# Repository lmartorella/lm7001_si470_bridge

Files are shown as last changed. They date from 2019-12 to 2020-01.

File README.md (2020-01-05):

# LM7001 FM tuner board upgrade to Si470x 

## Why

I needed a simple replacement for a vintage Pioneer Hi-fi radio tuner that tends to mute quite often. As most Pioneer units of 90's era, his MCU is the core part of the whole system (it receives the IR commands, it displays messages and implements the wake-up timers).

Luckily, the malfunctioning tuner board is based on the LM7001, a direct digital PLL synthesizer with simple serial interface. The PLL works perfectly, so the issue with the jittering sound should be in some other part of the tuner board.

After some hours spent to try to repair the board, I went for the simplest digital upgrade.

## The Silicon Labs module

It is very easy now to found a complete FM tuner with RDS for a couple of dollars from China suppliers. 

The most common core chip is the [Si4702](https://www.silabs.com/audio-and-radio/fm-radios/si4702-03-radio-receivers) from Silicon Labs.

His I2C interface makes it suitable for interfacing to virtually any MCU.

It exposes the mono/stereo state and the tuned flags via I2C: what we need to allow the original Pioneer display to show such information to the user, and to allow auto-scan.

## The Microchip MCU as interface

The computational power to decode the Pioneer MCU commands sent to the LM7001 requires little resources. So I picked up a discontinued but handy 4MHz PIC16F628 from my stock.

> Note: this old PIC supports very little debug facilities. In addition it doesn't support ICSP programming at 3.3V (WTF), so I added a manual jumper to in-circuit program my prototype. Consider any newer non-discontinued 8-bit PIC MCU as an upgrade for your projects. 

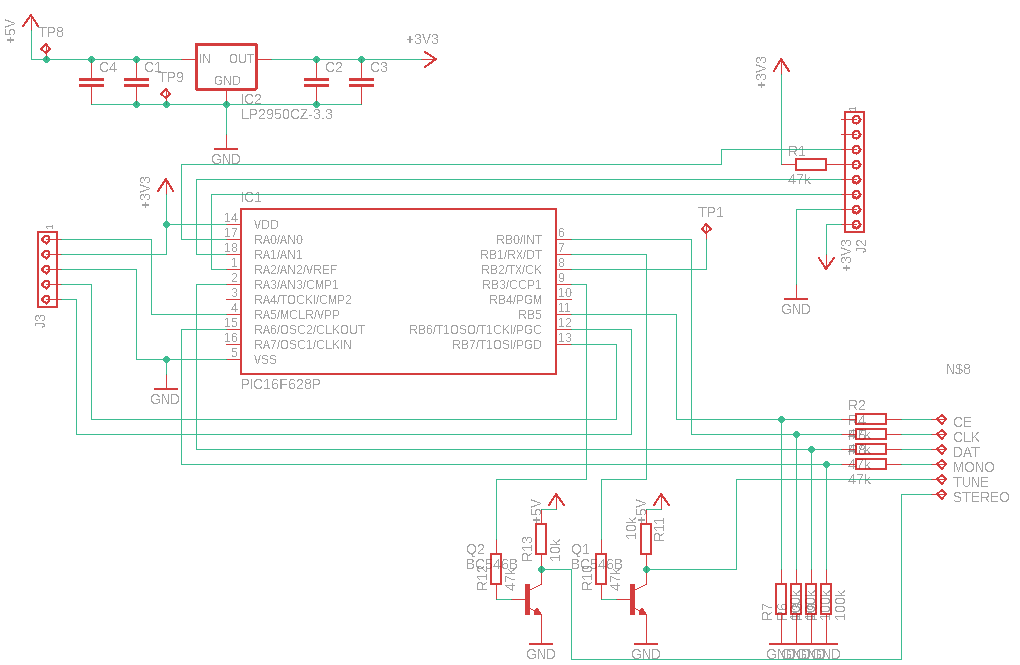
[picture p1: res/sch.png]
The schematic


In addition to decode the signals to control the LM7001, I wired the MONO signal and sent back the TUNED and STEREO lines as well. In that way all the Pioneer unit functions are fully functionals (all but the AM band).

The 5V TTL lines are converted to 3.3V inputs with resistors, and the two output converted back with a couple of NPNs.

The LM7001 lines are sampled using interrupts (RB0/INT for the chip enable line that triggers the start of transmission, and RB change for the clock line).

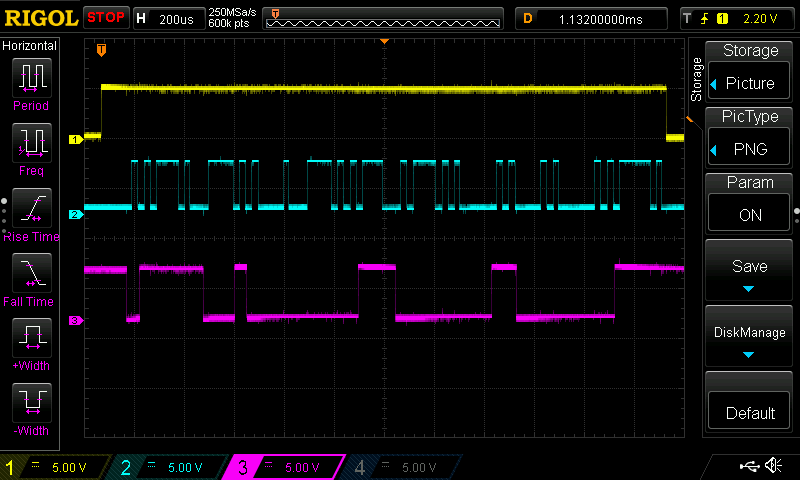
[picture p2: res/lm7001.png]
LM7001 timings

_The Pioneer MCU probably implemented the transmission in firmware due to the jittering of the high CLK line._

*IMPORTANT*: The response time from the end of tuning command to when the TUNED signal is drive high in case of valid FM station should be fast enough in order to let the Pioneer MCU to properly scan the frequencies in auto-scan mode.

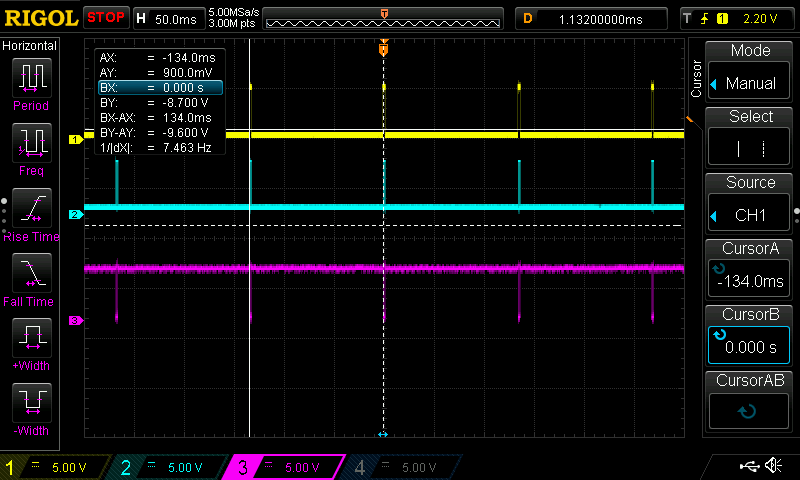
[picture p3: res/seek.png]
seeking

_In that case, it seems that the unit auto-scans with an interval of ~130ms._

## The final result

The modification here - not looking so professional with all these wires around - is however completely reversible for future reworks.

The board is manaully wired on a small piece of a prototype board to save bucks (but not to save time).

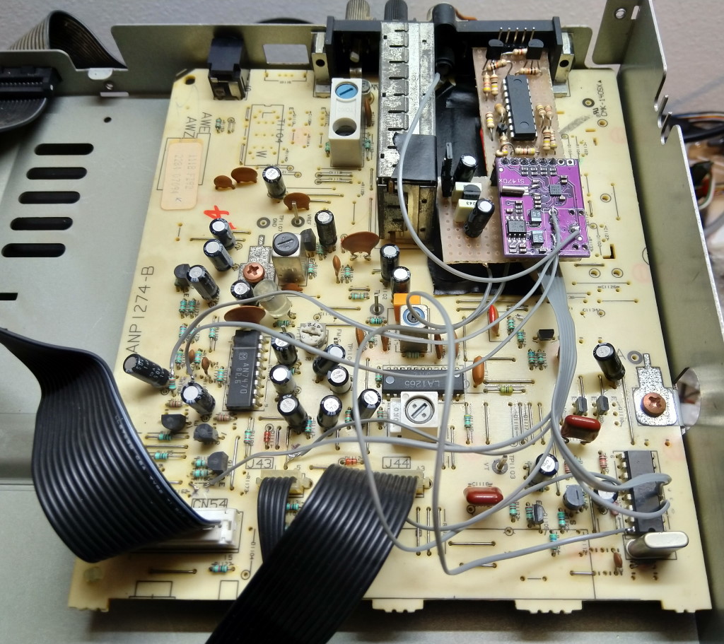
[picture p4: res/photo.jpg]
The board


It is fascinating to note that the whole tuner board now fits in the smaller 2x2mm chip in the purple module! The other bigger SSOP8 chip is the on-board headphone amplifier that I didn't even bother to remove.

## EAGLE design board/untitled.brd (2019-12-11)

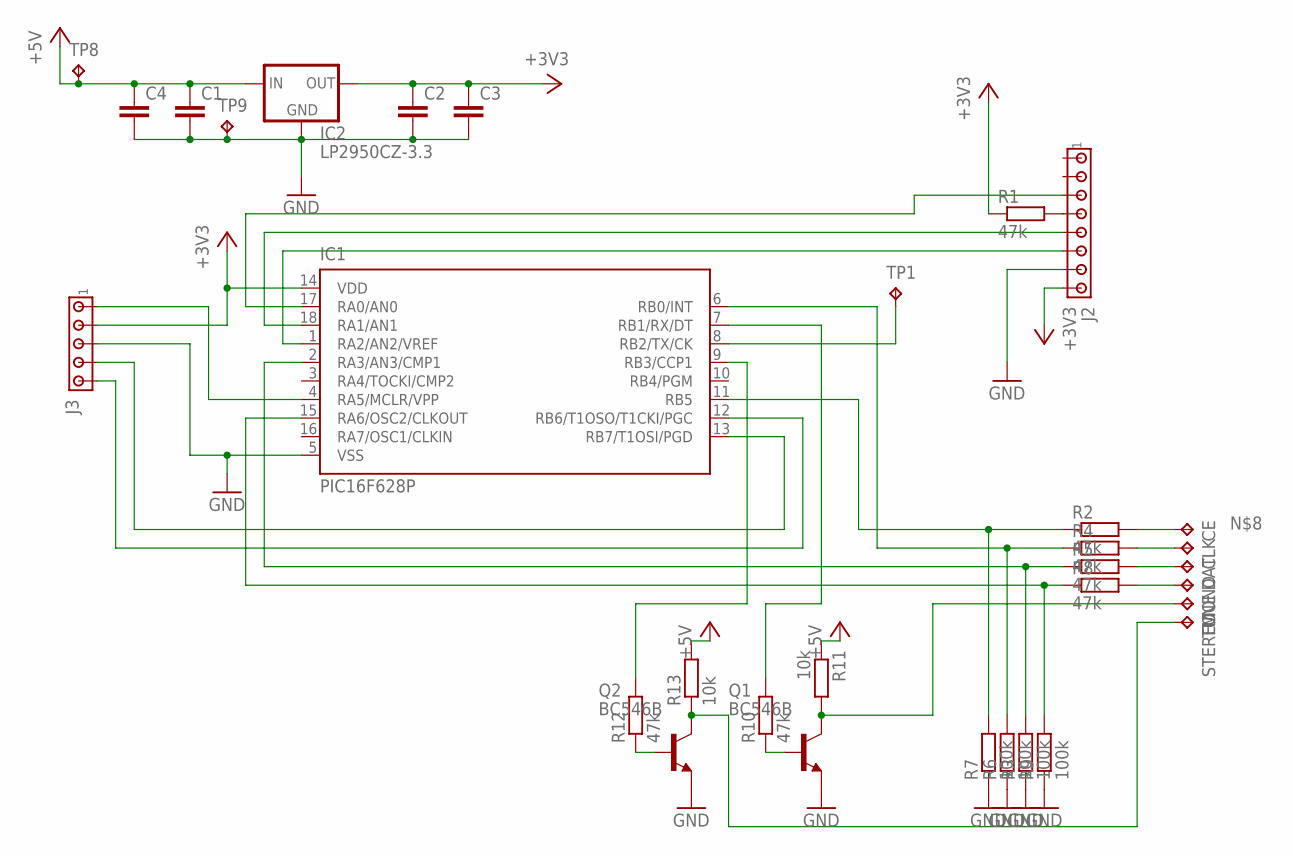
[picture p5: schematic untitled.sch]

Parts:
C1, C2, C3, C4: C-EU025-024X044; C025-024X044
CE: TPB1,27; B1,27
CLK: TPB1,27; B1,27
DAT: TPB1,27; B1,27
IC1: PIC16F628P; DIL18
IC2: LP2950CZ-3.3; TO92
J2: MTA08-100; 10X08MTA
J3: MTA05-100; 10X05MTA
MONO: TPB1,27; B1,27
Q1, Q2: BC546B; TO92-EBC
R1, R2, R4, R5, R8, R10, R12: 47k; 0204/7
R3, R6, R7, R9: 100k; 0204/7
R11, R13: 10k; 0204/7
STEREO: TPB1,27; B1,27
TP1, TP8, TP9: TPB1,27; B1,27
TUNE: TPB1,27; B1,27

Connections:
+3V3: C2.1, C3.1, IC1.14 (VDD), IC2.1 (OUT), J2.8, J3.2, R1.1
+5V: C1.1, C4.1, IC2.3 (IN), R11.1, R13.2, TP8.TP
GND: C1.2, C2.2, C3.2, C4.2, IC1.5 (VSS), IC2.2 (GND), J2.7, J3.3, Q1.E, Q2.E, R3.1, R6.1, R7.1, R9.1, TP9.TP
unnamed: IC1.4 (RA5/MCLR/VPP), J3.1
unnamed: IC1.1 (RA2/AN2/VREF), J2.6
unnamed: IC1.18 (RA1/AN1), J2.5
unnamed: IC1.13 (RB7/T1OSI/PGD), J3.4
unnamed: IC1.12 (RB6/T1OSO/T1CKI/PGC), J3.5
unnamed: J2.4, R1.2
unnamed: IC1.17 (RA0/AN0), J2.3
unnamed: CE.TP, R2.2
unnamed: IC1.8 (RB2/TX/CK), TP1.TP
unnamed: CLK.TP, R4.2
unnamed: DAT.TP, R5.2
unnamed: IC1.2 (RA3/AN3/CMP1), R3.2, R5.1
unnamed: IC1.6 (RB0/INT), R4.1, R6.2
unnamed: IC1.11 (RB5), R2.1, R7.2
unnamed: Q1.C, R11.2, TUNE.TP
unnamed: Q1.B, R10.1
unnamed: MONO.TP, R8.2
unnamed: IC1.15 (RA6/OSC2/CLKOUT), R8.1, R9.2
unnamed: Q2.C, R13.1, STEREO.TP
unnamed: IC1.7 (RB1/RX/DT), R10.2
unnamed: Q2.B, R12.1
unnamed: IC1.9 (RB3/CCP1), R12.2

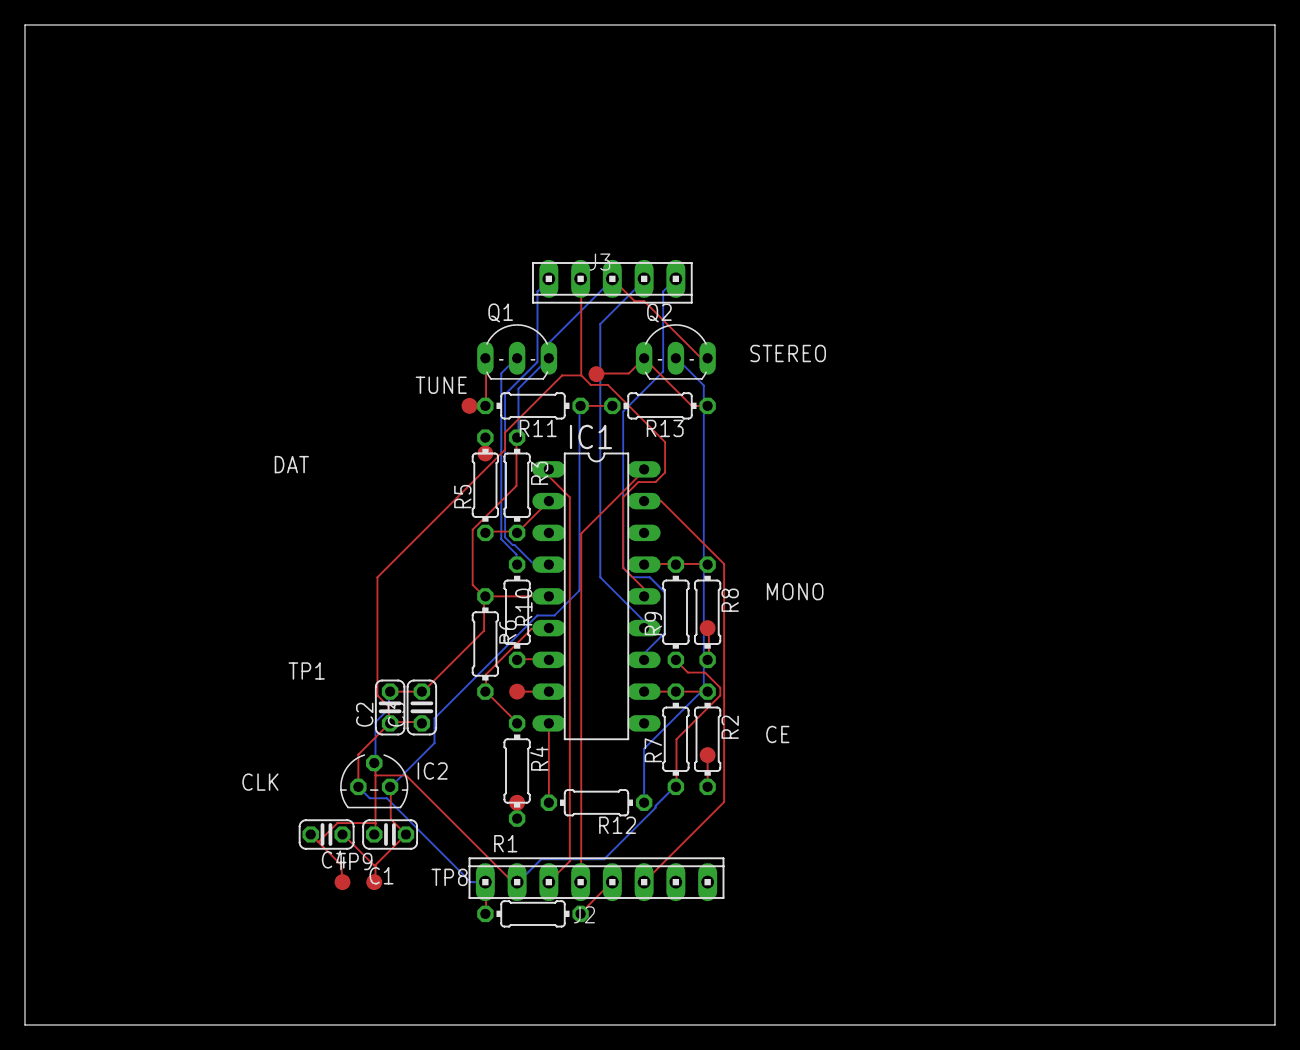
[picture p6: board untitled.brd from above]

Board: 2 copper layers, 100.0 x 80.0 mm, 32 parts (0 on the bottom side), 25 nets.

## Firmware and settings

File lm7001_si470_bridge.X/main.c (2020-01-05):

// CONFIG
#pragma config FOSC = INTOSCIO  // Oscillator Selection bits (INTOSC oscillator: I/O function on RA6/OSC2/CLKOUT pin, I/O function on RA7/OSC1/CLKIN)
#pragma config WDTE = ON        // Watchdog Timer Enable bit (WDT enabled)
#pragma config PWRTE = ON       // Power-up Timer Enable bit (PWRT enabled)
#pragma config MCLRE = ON       // RA5/MCLR/VPP Pin Function Select bit (RA5/MCLR/VPP pin function is MCLR)
#pragma config BOREN = OFF      // *** 3.3V! Brown-out Detect Enable bit (BOD enabled)
#pragma config LVP = OFF        // Low-Voltage Programming Enable bit (RB4/PGM pin has digital I/O function, HV on MCLR must be used for programming)
#pragma config CPD = OFF        // Data EE Memory Code Protection bit (Data memory code protection off)
#pragma config CP = OFF         // Flash Program Memory Code Protection bit (Code protection off)

// #pragma config statements should precede project file includes.
// Use project enums instead of #define for ON and OFF.

#include <stdint.h>
#include <xc.h>
#include "hw.h"
#include "si_fm_radio.h"

// When triggered to 1, data received from LM7001
static bit s_lmCeDeasserted;
static uint8_t s_lmDataCount;

typedef union {
    uint24_t data;
    struct {
        unsigned FREQ_LO: 8;
        unsigned FREQ_HI: 6; // 14 bit: steps of ref freqs, base 0
        unsigned TEST: 2; // always 0
        unsigned BAND_SELECTORS: 4; // regulates GPIOs
        unsigned REF_FREQ: 3;  // the base step frequency: 0: 100kHz, 4: 50kHz
        unsigned DIVIDER: 1; // 1: FM, 0: AM
    };
} LM_DATA;
static LM_DATA s_lmData;  // LSB are received first

void debug(DEBUG_CODES debugCode) {
    for (uint8_t i = 0; i < debugCode; i++) {
        DEBUG_TX_PORT = 1;
        DEBUG_TX_PORT = 0;
    }
}

/*
static void debug8(uint8_t data) {
    for (uint8_t i = 0; i < 8; i++) {
        DEBUG_TX_PORT = 1;
        if (data & 0x80) {
            NOP();
            NOP();
            NOP();
            NOP();
            NOP();
        }
        DEBUG_TX_PORT = 0;
        data <<= 1;
    }
}
*/

// Decode data received from Pioneer MCU. Not time critical, Pioneer
// waits > 100ms between an update to the next
static void decodeLmData() {    
    if (s_lmData.DIVIDER != 1 || s_lmData.TEST != 0 || s_lmData.REF_FREQ != 4) {
        // Invalid (AM or invalid data)
        si_fm_mute(1);
        debug(DEBUG_INVALID_CODE);
    } else {      
        //debug8(s_lmData.FREQ_LO);
        //debug8(s_lmData.FREQ_HI);
        
        uint16_t freq = (s_lmData.FREQ_LO | (s_lmData.FREQ_HI << 8)) - (875 * 2) - (107 * 2); // Base is 87.5 , subtract IF too
        if (freq > 410) { // (108 - 87.5 Mhz) / 50 kHz
            debug(DEBUG_INVALID_CODE);
        } else {
            // This will unmute
            si_fm_tune(freq);
            debug(DEBUG_VALID_CODE);
        }
    }
}

static bit s_dat;
static void __interrupt interruptVector() {    
    // Sample it here to be closer to the clock raising edge
    s_dat = MCU_DAT_PORT;
    // If CE is low, deassert everything and process data, if count == 24 is valid
    if (!MCU_CE_PORT) {
        s_lmCeDeasserted = 1;
    } else if (INTCONbits.INTF) {
        // else INTF. Sample data
        s_lmData.data >>= 1;
        if (s_dat) {
            s_lmData.data |= 0x800000;
        }
        s_lmDataCount++;
    }

    // Reset interrupt flags
    INTCONbits.RBIF = 0;
    INTCONbits.INTF = 0;
}

void main(void) {
    CLRWDT();
    // Assign prescaler to WDT. 1:256
    OPTION_REGbits.PSA = 1;
    OPTION_REGbits.PS = 7;
    OPTION_REGbits.T0CS = 0;
    CLRWDT();
    // Wdt now up to 2.3s
    
    // Disable comparators to use full porta
    CMCON = 7;
    
    DEBUG_TX_TRIS = 0;
    NOP();
    DEBUG_TX_PORT = 0;
        
    // Init LM7001 interface 
    MCU_CE_TRIS = MCU_CLK_TRIS = MCU_DAT_TRIS = 1;
    MCU_MONO_TRIS = 1;
    
    MCU_TUNE_TRIS = MCU_STEREO_TRIS = 0;
    MCU_TUNE_PORT = MCU_STEREO_PORT = 0;
            
    // Init interrupts. Only RB change and INT enabled
    INTCON = 0;
    INTCONbits.RBIE = 1;
    INTCONbits.INTE = 1;
    // Data sampled on rising edge
    OPTION_REGbits.INTEDG = 1;
    // Enable pull-up to avoid spurious RB change interrupts
    OPTION_REGbits.nRBPU = 1;
            
    // Init SI module
    si_fm_init();
    
    // Now setup LM port
    // Wait until CE is deasserted
    s_lmCeDeasserted = 0;
    s_lmDataCount = 0;
    while (MCU_CE_PORT);

    debug(DEBUG_RESET);
    
    // Start receiving data
    INTCONbits.GIE = 1;

    // Loop
    while (1) {
        CLRWDT();
        uint8_t dataValid = 0;
        
        // Data packet received?
        if (s_lmCeDeasserted) {
            s_lmCeDeasserted = 0;
            dataValid = s_lmDataCount == 24;
            s_lmDataCount = 0;
        }

        if (dataValid) {
            //DEBUG_TX_PORT = 1;
            // Data valid. Decode it and send it to SI, decouple it from the buffer
            // so next packets can be received
            decodeLmData();
        }
        
        // Propagate MONO command
        si_fm_forceMono(MCU_MONO_PORT);
        
        // Poll status and update output STEREO and SIGNAL lines
        si_fm_pollStatus();
        // Update the output line as soon as possible for the Pioneer MCU seek algo
        MCU_TUNE_PORT = si_fm_isTuned() ? 0 : 1;
        MCU_STEREO_PORT = si_fm_isStereo() ? 1 : 0;
        si_fm_postStatus();
    }
}

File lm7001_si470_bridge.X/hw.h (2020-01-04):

// PIC 16F628A
// FOSC 4MHz (internal)
#define _XTAL_FREQ 4000000

// RB1/RB2 (RX/TX) for future expansions and for debug
// RB4/RB6/RB7 for programming interface

#define DEBUG_TX_TRIS TRISBbits.TRISB2
#define DEBUG_TX_PORT PORTBbits.RB2

/**
 * Si4703 interface
 */
// Reset pin
#define SI_RES_TRIS TRISAbits.TRISA0
#define SI_RES_PORT PORTAbits.RA0
// SCK
#define SI_SCK_TRIS TRISAbits.TRISA1
#define SI_SCK_PORT PORTAbits.RA1
// SDA
#define SI_SDA_TRIS TRISAbits.TRISA2
#define SI_SDA_PORT PORTAbits.RA2

/**
 * LM7001 driver interface from Pioneer MCU
 */
// CE on RB5 for interrupt on change
#define MCU_CE_TRIS TRISBbits.TRISB5
#define MCU_CE_PORT PORTBbits.RB5
// Clock on RB0 for interrupt on edge rising
#define MCU_CLK_TRIS TRISBbits.TRISB0
#define MCU_CLK_PORT PORTBbits.RB0

#define MCU_DAT_TRIS TRISAbits.TRISA3
#define MCU_DAT_PORT PORTAbits.RA3

// MONO is active high
#define MCU_MONO_TRIS TRISAbits.TRISA6
#define MCU_MONO_PORT PORTAbits.RA6

// TUNE is active low
#define MCU_TUNE_TRIS TRISBbits.TRISB1
#define MCU_TUNE_PORT PORTBbits.RB1

// STEREO is unknown
#define MCU_STEREO_TRIS TRISBbits.TRISB3
#define MCU_STEREO_PORT PORTBbits.RB3

typedef enum {
    DEBUG_VALID_CODE = 1,
    DEBUG_INVALID_CODE = 2,
    DEBUG_RESET = 3
}
DEBUG_CODES;
void debug(DEBUG_CODES debugCode);

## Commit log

2019-12-01 - Working at protocol bridge, first commit
    [untitled.brd, untitled.sch]
2019-12-05 WIP test in isolation
    [untitled.brd, untitled.sch]
2019-12-09 - Splitting files to test with Raspberry
2019-12-11 - Fixed i2c
2019-12-11 - Added notes
    [untitled.brd, untitled.sch]
2020-01-04 Fixed boot timing issues Reenabled WDT
    [hw.h, main.c, si_fm_radio.c]
2020-01-05 - Added docs
    [untitled.sch]
